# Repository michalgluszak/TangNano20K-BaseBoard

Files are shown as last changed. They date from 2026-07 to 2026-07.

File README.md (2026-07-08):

# Tang Nano 20K Evaluation Board

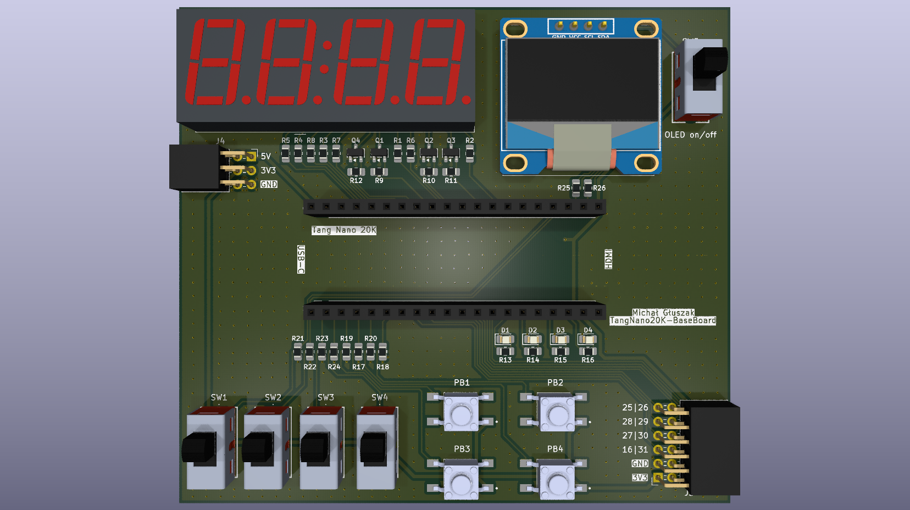
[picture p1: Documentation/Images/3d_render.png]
3D Render


## About the Project

The **Tang Nano 20K Evaluation Board** is a custom motherboard designed to make learning and prototyping digital circuits easier using Hardware Description Languages (HDL), like Verilog and VHDL.

The idea for this project came from a desire to test written code in practice. Commercial evaluation platforms, like Basys 3 or boards based on Artix 7 chips, are relatively expensive. As an alternative, I chose the Tang Nano 20K chip, which offers great features at a very affordable price (around 120 PLN). To make working with this module easier, I designed a dedicated expansion board.

A huge advantage of this solution is its modularity – the Tang Nano 20K module is not soldered permanently. It is placed in pin headers, so you can take it out anytime and use it in another project directly on a breadboard.

## Features

* **Budget-friendly alternative:** A full evaluation environment for learning FPGA at a fraction of the cost of commercial solutions.
* **Modularity (Plug & Play):** The ability to easily remove the Tang Nano chip and use it outside the motherboard.
* **Data visualization:** Built-in **4 LEDs**, a **4-digit 7-segment display** (perfect for testing things like BCD decoders or counters), and support for an **OLED screen**, which makes viewing results and fast code debugging much easier.
* **Input interface:** The board has **4 push-buttons** and **4 slide switches**, which are necessary for manually setting logic states (0/1) and testing state machines.
* **Expandability (PMOD):** An integrated PMOD standard connector allows you to easily connect a wide range of external peripheral modules, such as sensors (e.g., temperature), converters, or additional interfaces.

## PCB Technical Specifications

Due to the nature of FPGA chips and fast digital signals, during the PCB design in KiCad, I put special focus on Signal Integrity and the elimination of electromagnetic interference (EMI).

* **Board dimensions:** 100 mm x 90 mm.
* **Signal trace width (0.25 mm):** Routed tightly and compactly to minimize their length and delays.
* **Power trace width (0.6 mm):** Widened to ensure proper current capacity and a stable voltage for the FPGA chip.
* **Single-layer topology (almost):** All routing of signal and power traces was done on the top layer (Top Layer). I only moved one trace to the bottom layer (Bottom Layer) because there was no space on top. Thanks to this, the bottom layer is an unbroken return plane.
* **Ground Planes:** I applied ground planes (GND copper pours) on both layers (Top and Bottom), which provides excellent shielding.
* **Via Stitching:** To balance potentials and minimize ground loop impedance, I connected the top and bottom GND planes using a large number of stitching vias. This is a key technique for reducing noise in high-frequency digital circuits.

## Schematic

The schematic is divided into logical blocks: Tang Nano 20K Connectors, User LEDs, GPIO Expansion Headers, 4-Digit 7-Segment Display, Push Buttons, Slide Switches, and OLED Display (I2C).

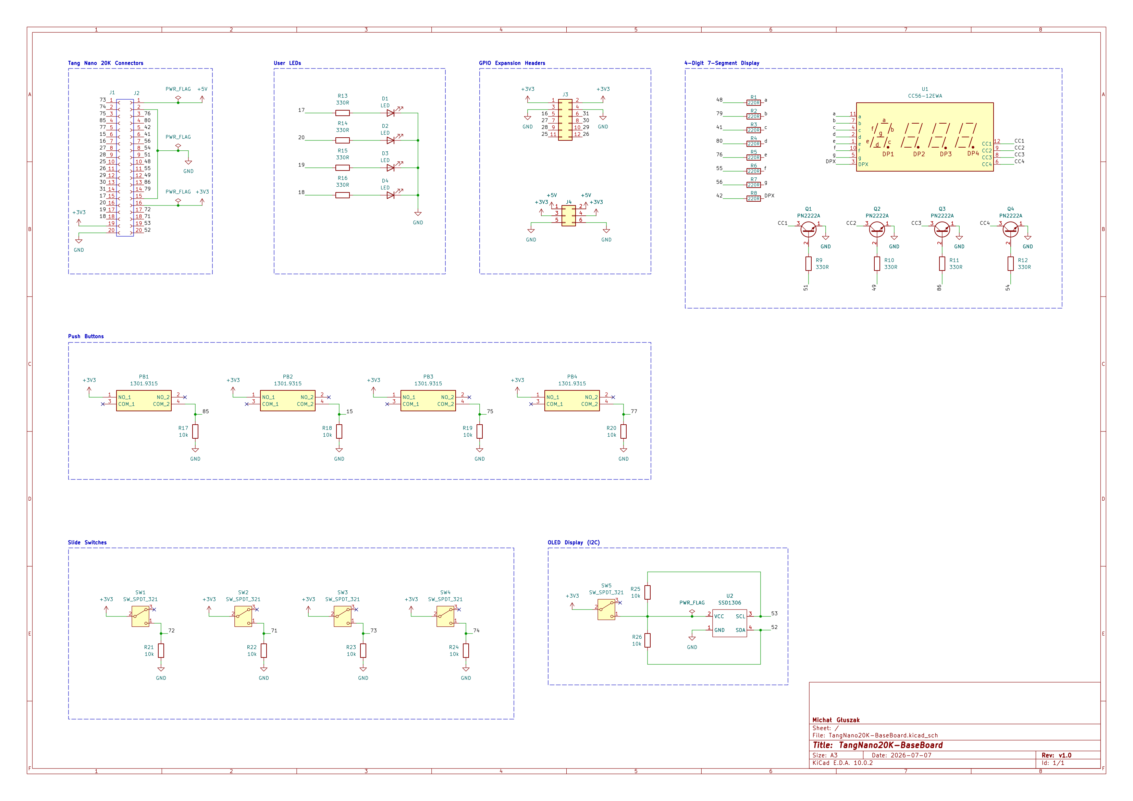
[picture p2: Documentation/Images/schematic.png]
Schematic


## PCB Design

Below is a screenshot of the finished PCB design showing the routing and the via stitching structure.

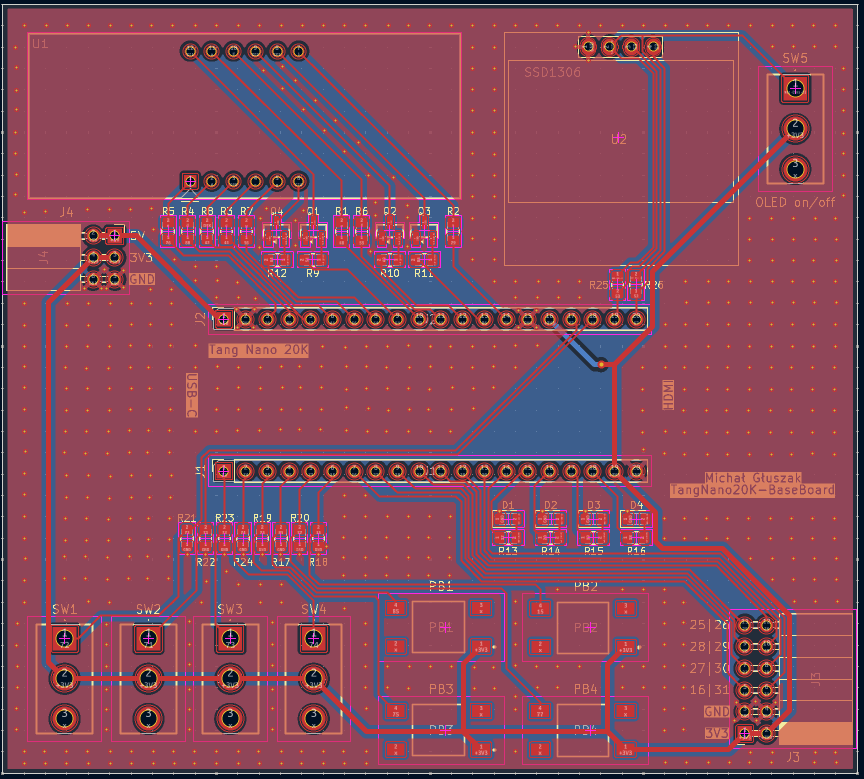
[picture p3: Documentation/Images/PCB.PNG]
PCB View


**Top Layer:**
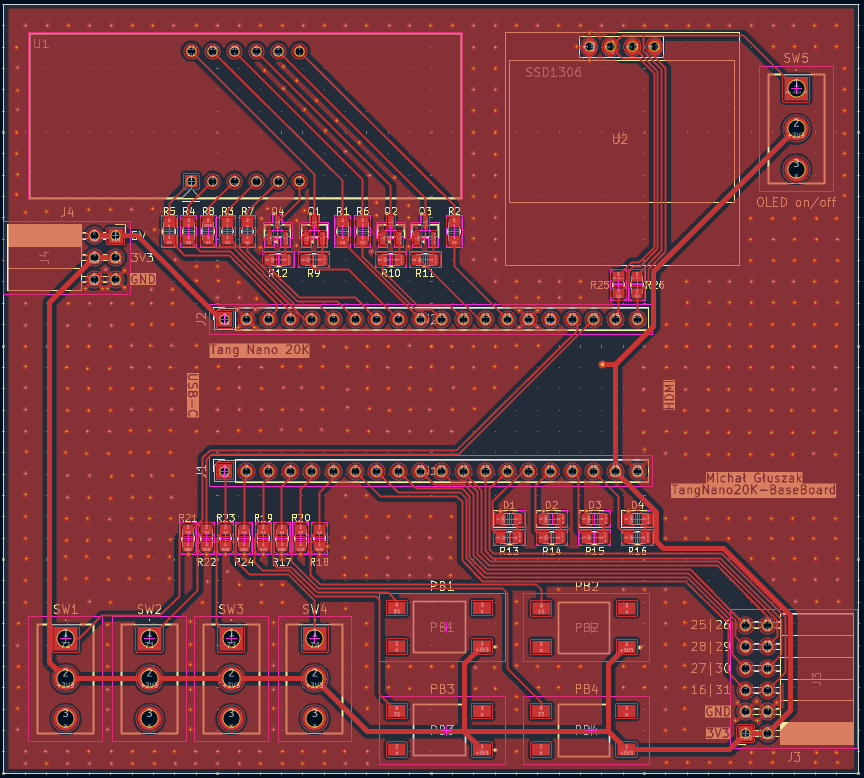
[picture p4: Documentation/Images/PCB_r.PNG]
PCB Top Layer


**Bottom Layer:**
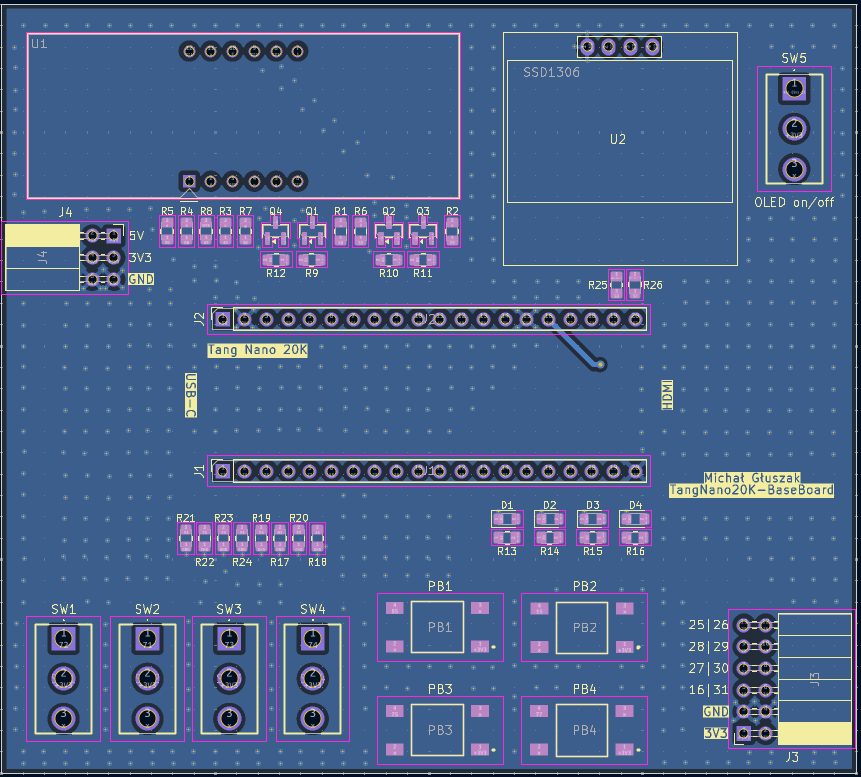
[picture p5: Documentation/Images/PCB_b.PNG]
PCB Bottom Layer


## Bill of Materials (BOM)

To make the review and assembly of the board easier, I generated an interactive Bill of Materials (BOM). You can closely inspect the routing and component placement there.

👉 **[Open Interactive BOM](https://michalgluszak.github.io/TangNano20K-BaseBoard/Documentation/bom/ibom.html)**

---
*Project created in KiCad 10.0.*

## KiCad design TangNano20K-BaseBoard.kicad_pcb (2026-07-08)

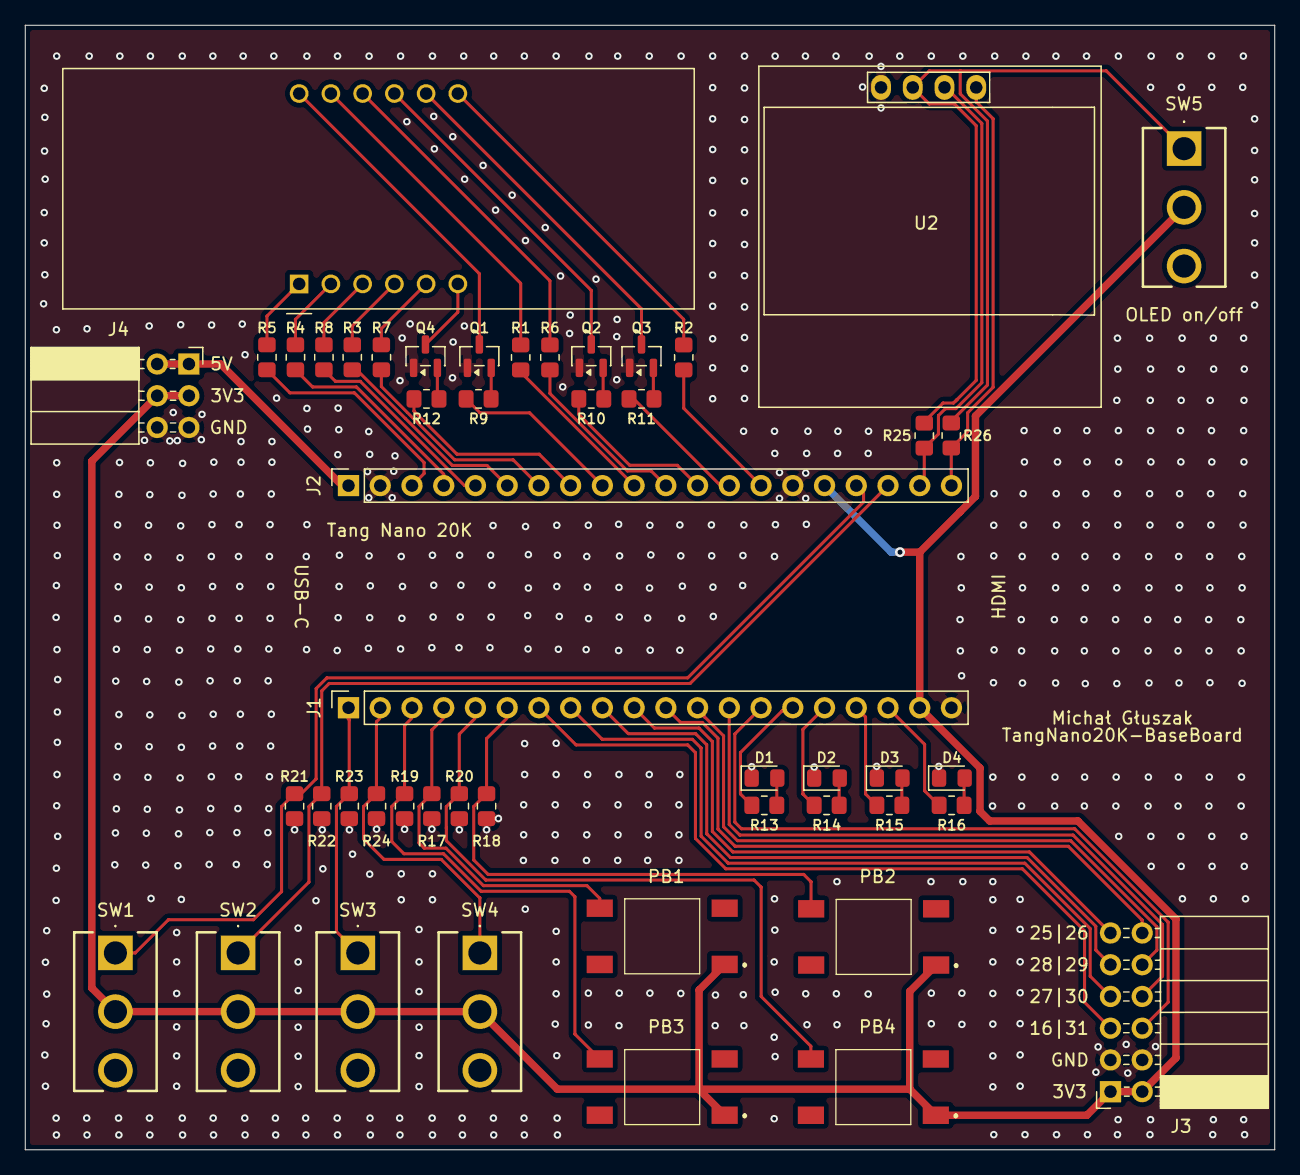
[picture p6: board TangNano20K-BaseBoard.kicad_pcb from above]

Board: 2 copper layers, 100.0 x 90.0 mm, 49 parts (0 on the bottom side), 58 nets.

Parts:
D1, D2, D3, D4: LED; LED_0805_2012Metric_Pad1.15x1.40mm_HandSolder
J1, J2: Conn_01x20_Socket; PinSocket_1x20_P2.54mm_Vertical
J3: Conn_02x06_Odd_Even; PinSocket_2x06_P2.54mm_Horizontal
J4: Conn_02x03_Odd; PinSocket_2x03_P2.54mm_Horizontal
PB1, PB2, PB3, PB4: 1301.9315; 13019319
Q1, Q2, Q3, Q4: PN2222A; SOT-23
R1, R2, R3, R4, R5, R6, R7, R8: 220R; R_0805_2012Metric_Pad1.20x1.40mm_HandSolder
R9, R10, R11, R12, R13, R14, R15, R16: 330R; R_0805_2012Metric_Pad1.20x1.40mm_HandSolder
R17, R18, R19, R20, R21, R22, R23, R24, R25, R26: 10k; R_0805_2012Metric_Pad1.20x1.40mm_HandSolder
SW1, SW2, SW3, SW4, SW5: SW_SPDT_321; SL19121
U1: CC56-12EWA; CA56-12EWA
U2: SSD1306; 128x64OLED

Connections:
+3V3: J1.19, J2.16, J3.1, J3.2, J4.3, J4.4, PB1.1 (NO_1), PB2.1 (NO_1), PB3.1 (NO_1), PB4.1 (NO_1), SW1.2 (B), SW2.2 (B), SW3.2 (B), SW4.2 (B), SW5.2 (B)
+5V: J2.1, J4.1, J4.2
/15: J1.6, PB2.4 (COM_2), R18.2
/16: J1.7, J3.5
/17: J1.15, R13.1
/18: J1.18, R16.1
/19: J1.17, R15.1
/20: J1.16, R14.1
/25: J1.10, J3.11
/26: J1.11, J3.12
/27: J1.8, J3.7
/28: J1.9, J3.9
/29: J1.12, J3.10
/30: J1.13, J3.8
/31: J1.14, J3.6
/41: J2.6, R3.1
/42: J2.5, R8.1
/48: J2.10, R1.1
/49: J2.12, R10.2
/51: J2.9, R9.2
/52: J2.20, R26.1, U2.4 (SDA)
/53: J2.19, R25.2, U2.3 (SCL)
/54: J2.8, R12.2
/55: J2.11, R6.1
/56: J2.7, R7.1
/71: J2.18, R22.2, SW2.1 (C)
/72: J2.17, R21.2, SW1.1 (C)
/73: J1.1, R23.2, SW3.1 (C)
/74: J1.2, R24.2, SW4.1 (C)
/75: J1.3, PB3.4 (COM_2), R19.2
/76: J2.3, R5.1
/77: J1.5, PB4.4 (COM_2), R20.2
/79: J2.14, R2.1
/80: J2.4, R4.1
/85: J1.4, PB1.4 (COM_2), R17.2
/86: J2.13, R11.2
/CC1: Q1.3 (C), U1.12 (CC1)
/CC2: Q2.3 (C), U1.9 (CC2)
/CC3: Q3.3 (C), U1.8 (CC3)
/CC4: Q4.3 (C), U1.6 (CC4)
/DPX: R8.2, U1.3 (DPX)
/a: R1.2, U1.11 (a)
/b: R2.2, U1.7 (b)
/c: R3.2, U1.4 (c)
/d: R4.2, U1.2 (d)
/e: R5.2, U1.1 (e)
/f: R6.2, U1.10 (f)
/g: R7.2, U1.5 (g)
GND: D1.1 (K), D2.1 (K), D3.1 (K), D4.1 (K), J1.20, J2.2, J2.15, J3.3, J3.4, J4.5, J4.6, Q1.1 (E), Q2.1 (E), Q3.1 (E), Q4.1 (E), R17.1, R18.1, R19.1, R20.1, R21.1, R22.1, R23.1, R24.1, U2.1 (GND)
unnamed: D1.2 (A), R13.2
unnamed: D2.2 (A), R14.2
unnamed: D3.2 (A), R15.2
unnamed: D4.2 (A), R16.2
unnamed: Q1.2 (B), R9.1
unnamed: Q2.2 (B), R10.1
unnamed: Q3.2 (B), R11.1
unnamed: Q4.2 (B), R12.1
unnamed: R25.1, R26.2, SW5.1 (C), U2.2 (VCC)

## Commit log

2026-06-27 Add all files
    [TangNano20K-BaseBoard.kicad_pcb, TangNano20K-BaseBoard.kicad_sch]
2026-06-27 Add electronic schematic
    [TangNano20K-BaseBoard.kicad_sch]
2026-06-27 Add footprint for electronic element
    [TangNano20K-BaseBoard.kicad_sch]
2026-06-27 Update schematic, add new symbol, footprint and 3d model
    [TangNano20K-BaseBoard.kicad_pcb, TangNano20K-BaseBoard.kicad_sch]
2026-06-27 Update schematic and start design pcb layout
    [TangNano20K-BaseBoard.kicad_pcb, TangNano20K-BaseBoard.kicad_sch]
2026-06-27 Update SW1, SW2, SW3, SW4, SW5
    [TangNano20K-BaseBoard.kicad_pcb]
2026-06-28 Update schematic and pcb
    [TangNano20K-BaseBoard.kicad_pcb, TangNano20K-BaseBoard.kicad_sch]
2026-06-28 Big Update
    [TangNano20K-BaseBoard.kicad_pcb, TangNano20K-BaseBoard.kicad_sch]
2026-07-03 Update PCB
    [TangNano20K-BaseBoard.kicad_pcb]
2026-07-03 Update schematic
    [TangNano20K-BaseBoard.kicad_sch]
2026-07-08 Add bom folder
2026-07-08 Update README.md, add link to bom file
